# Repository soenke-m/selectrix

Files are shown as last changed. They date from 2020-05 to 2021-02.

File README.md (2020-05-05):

# selectrix

Ich baue und entwickle Hard- und Software für das Selectrix-System

Hier möchte ich gerne meine SX-Projeke  mit euch Teilen damit alle die Selectrix einsetzen wollen davon profitieren können.

Die Projekte basieren auf den Atmel ATtiny Microcontroler und sind mit Atmel Studio 7 erstellt. 
Zum Testen steht mir eine FCC zur Verfügung.

Der Nachbau und die Benutzung der Hardware geschieht auf eigene Gefahr, ich hafte nicht für Schäden, die der Anwender oder Dritte durch die Verwendung verursachen.

Alle Daten sind lizensiert unter der <a href="http://creativecommons.org/licenses/by-nc-sa/4.0/">Attribution-NonCommercial-ShareAlike 4.0 International</a>. - die eine private Weiterverwertung erlaubt, solange in angemessener Weise die Urheberschaft erwähnt wird und die abgeleitete Arbeit unter der gleichen Lizenz steht.

<a title="Mateo Zlatar / Public domain" href="https://commons.wikimedia.org/wiki/File:Open-source-hardware-logo.svg">Open-source-hardware-logo</a>

<br />Dieses Werk ist lizenziert unter einer <a rel="license" href="http://creativecommons.org/licenses/by-nc-sa/4.0/">Creative Commons Namensnennung - Nicht-kommerziell - Weitergabe unter gleichen Bedingungen 4.0 International Lizenz</a>.

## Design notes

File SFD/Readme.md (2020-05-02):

# SFD-V1-Universeller Funktionsdecoder für den SX-Bus

Verwendung:

-	Magnetartikel
-	Beleuchtung
-	Weichen
-	Signale (Haupt/Vorsignalsteuerung)
-	Bahnübergänge (mit/ohne Schranke)

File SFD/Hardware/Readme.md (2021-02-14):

Dieser Ordner enthält die Eagle Dateien

Die DIN-Stecker Version ist eine einseitige Platine

Es existiert ein <a href="https://www.reichelt.de/my/1683631">Reichel Warenkorb</a>. Die Teileliste ist für beide Versionen gültig. Die nicht benötigten Teile müssen dann gelöscht werden.

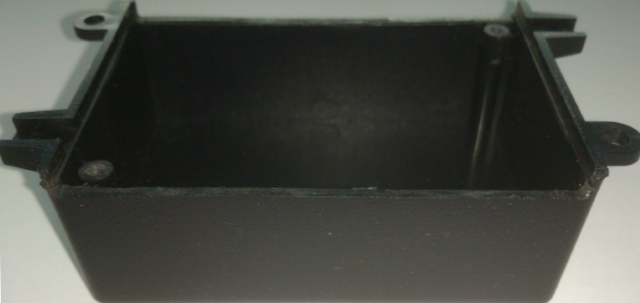
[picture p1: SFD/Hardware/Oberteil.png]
Oberteil


Das Gehäuseoberteil muss an den Längsseiten um 4mm gekürzt werden. Die Schraubendome müssen auf dieses Niveau abgefeilt werden. Die Platine wird dann zwischen beide Gehäusehälften eingeklemmt.

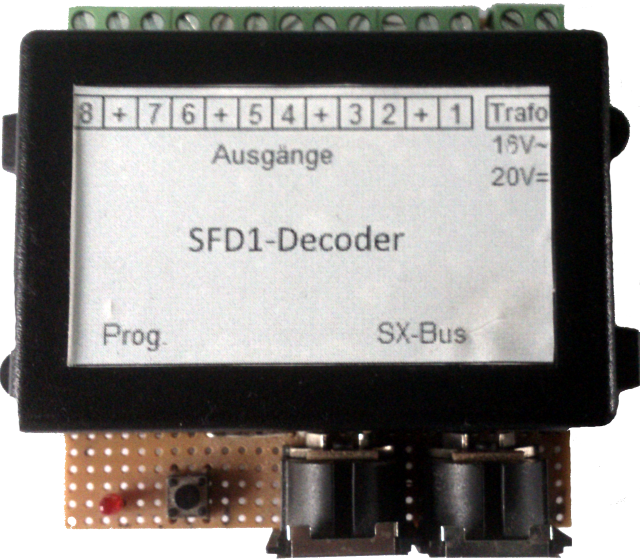
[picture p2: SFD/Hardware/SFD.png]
SFD


Das Bild zeigt noch den Prototyp mit Lochstreifenplatine.

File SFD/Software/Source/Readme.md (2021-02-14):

Die Software ist unter Atmel Studio 7.0 entwickelt und kompiliert.
Teile der Software sind aus Platz- und Geschwindigkeitsgründen in Assembler geschrieben. 
Ich hoffe die Kommentare sind verständlich.

Mit Optimierung -Os kompilieren, sonst passt der Code nicht ins Flash. 

Fuses: Interner Oszillator, Kein Clock-Div, Brown_Out_Detection 4V3.

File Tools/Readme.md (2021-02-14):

# Decoderprogramer

Dieses Tool dient zum Einstellen der Decoderparameter. Es sollte ab WinXP laufen.
Erklärung zur Bedienung stehen in der SFD-Doku. Das Programm läuft ohne Installation.

ACHTUNG !! Die Benutzung des Programms geschieht auf eigene Gefahr. Ich hafte nicht für Schäden die der Anwender oder Dritte durch die Verwendung verursachen.

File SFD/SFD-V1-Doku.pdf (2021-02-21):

Signal- u. Funktionsdecoder | SFD-V1 | Funktions- u. Parameterbeschreibung

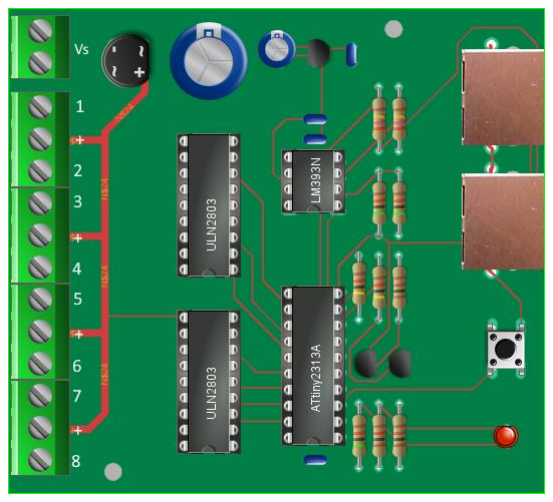
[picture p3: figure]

© 2021 Sönke Marsch | 1

SFD-V1-Universeller Funktionsdecoder für den SX-Bus

### Verwendung:

- Magnetartikel
- Beleuchtung
- Weichen
- Signale (Haupt/Vorsignalsteuerung)
- Bahnübergänge (mit/ohne Schranke)

Der SFD-V1 ist ein DIY Signal- und Funktionsdecoder. Die Platine kann in ein Kleingehäuse eingebaut werden.

Spannungsversorgung: Micro und Logik über den SX-Bus
Last Teil über Ext. – Klemmen Vss : max. 16V∿, 20V⎓
Anschlüsse: | 2 x RJ45 für den SX-Bus 1 x 2-pol. Schraubklemme für die Ext. – Stromversorgung (Vss) 4 x 3-pol. Schraubklemmen für die Ausgänge. Die Masse wird geschaltet. Die mittlere Klemme der 3er Gruppen ist mit dem Pluspol der Ext. – Stromversorgung verbunden. Ausgangsstrom max. 1 A pro Ausgang (nicht Kurzschlussfest). Max. 1,5 A alle Ausgänge zusammen.

Betriebsart:
0. 8 Schalt- / Impulsausgänge
1. 8 Schaltausgänge für Beleuchtung
2. 4 Weichen Impuls oder Dauerbetrieb
3. 2 Weichen und 1 Bahnübergang
4. 4 Blocksignale
5. 2 Einfahrsignale mit Vorsignal
6. 2 Haupt/Sperrsignale
7. 1 Einfahrsignale mit Vorsignal und 1 unabhängiges dreibegriffiges Vorsignal
8. 1 Haupt/Sperrsignal und 1 unabhängiges dreibegriffiges Vorsignal
| Ab Mode 9 mit Dunkeltastung des Vorsignals bei hp00 hp0 / sh1 des Hauptsignals
9. 1 Haupt/Sperrsignal u. 1 Blocksignal mit Vorsignal am Mast des Hauptsignal
10. 1 Einfahrsignal mit Vorsignal und 1 dreibegriffiges Vorsignal am Mast des HS
11. 1 Haupt/Sperrsignal und 1 dreibegriffiges Vorsignal am Mast des Hauptsignal

Bei allen Weichenmodi kann die letzte Weichenstellung gespeichert werden.

Alle Signal- und Bahnübergangmodi sind gedimmt (Glühlampensimulation).

Bei den Signalmodi wird nach einer Änderung erst das alte Signalbild ab gedimmt und danach das neue Signalbild auf gedimmt.

Decoderparameter:

Parameter | Wert | Mode | Bemerkungen
0 | 0 – 11 | - | Betriebsart: (Mode) | Default 2
0 | - | 8 Schaltausgänge Impuls- oder Dauerbetrieb
1 | - | 8 Schaltausgänge gedimmt (Glühlampensimulation)
| 2 | - | 4 Weichen Impuls- oder Dauerbetrieb
| 3 | - | 2 Weichen und 1 Bahnübergang
| 4 | - | 4 Blocksignale
| 5 | - | 2 Einfahrsignale mit Vorsignale
| 6 | - | 2 Haupt/Sperrsignale
7 | - | 1 Einfahrsignale mit Vorsignal und 1 dreibegriffiges Vorsignal
8 | - | 1 Haupt/Sperrsignal und 1 dreibegriffiges Vorsignal
| 9 | -

1 Haupt/Sperrsignal 1 Blocksignal mit Vorsignal am Mast des Haupt/Sperrsignal. Mit Dunkeltastung des Vorsignals

| 10 | -

1 Einfahrsignal mit Vorsignal und 1 dreibegriffiges Vorsignal am Mast des Einfahrsignals. Mit Dunkeltastung des Vorsignals

| 11 | -

1 Haupt/Sperrsignal und 1 dreibegriffiges Vorsignal am gleichen
| | | Mast mit Dunkeltastung des Vorsignals
1 | 3 – 103 | 0 – 11 | 1. Decoderadresse | Default 15
2 | 0 – 3 | 0 – 11 | 1. Subadresse | Default 0
3 | 3 – 103 | 5 – 11 | 2. Decoderadresse | Default 16
4 | 0 – 3 | 5 – 11 | 2. Subadresse | Default 0
5 | 0 – 63 | 0, 2, 3 | Impulsdauer 0 = Dauerbetrieb | Default 20 ≙ 400 ms
6 | 1 – 255 | 1 | Multiplikator für Zufallssteuerung | Default 20 ≙ 0,4 – 6,4 sek
7 | 1 – 255 | 3 | Dauer Gelbphase am Bahnübergang | Default 75 ≙ 1,5 sek
8 | 1 – 255 | 3 | Verzögerung bis Schrankenantrieb ein | Default 125 ≙ 2,5 sek
9 | 1 – 255 | 3 | Impulsdauer für Schrankenantrieb | Default 25 ≙ 0,5 sek
10 | 0 – 255 | - | Optionen: | Default 00000000
Bit 1 | 7 – 11 | 1 = Fahrstraßenabhängige Vorsignalsteuerung
Bit 2 | 5 – 11 | 1 = Alternative Ansteuerung für mehrbegriffige Signale
Bit 3 | 3 | 1 = Bahnübergang mit Lichtzeichenanlage
Bit 4 | 3 | 1 = Impulsbetrieb für Schrankenantrieb
Bit 5 | 2 + 3 | 1 = Speichern der letzten Weichenstellung
| Bit 6 | 1 | 1 = Neonleuchten-Simulation
Bit 7 | 1 | 1 = Simultansteuerung. D.h. Werte > 0 schaltet alle Lampen an
| Bit 8 | 1

1 = Zufallssteuerung. D.h. die Lampen werden zufällig eingeschaltet. Nur in Verbindung mit Simultansteuerung (Bit 7=1)
11 | 0 – 255 | 7 – 11 | Maske für fahrstraßenabh. Vorsignalsteuerung: Default 00000000
Bit 1 | 7 – 11 | Fahrstraße 1 | 0 = inaktiv, 1 = aktiv
Bit 2 | 7 – 11 | Fahrstraße 2 | 0 = inaktiv, 1 = aktiv
Bit 3 | 7 – 11 | Fahrstraße 3 | 0 = inaktiv, 1 = aktiv
| Bit 4 | 7 – 11 | Nicht benutzt
Bit 5 | 7 – 11 | Fahrstraße 1 | Bit 1 0 od. 1 aktiv
Bit 6 | 7 – 11 | Fahrstraße 2 | Bit 2 0 od. 1 aktiv
Bit 7 | 7 – 11 | Fahrstraße 3 | Bit 3 0 od. 1 aktiv
| Bit 8 | 7 – 11 | Nicht benutzt
12 | 3 – 104 | 7 – 11 | Signaladresse Standartfahrstraße | Default 17
13 | 0 – 3 | 7 – 11 | Subadresse Standartfahrstraße | Default 0
14 | 3 – 104 | 7 – 11 | Signaladresse Fahrstraße 1 | Default 18
15 | 0 – 3 | 7 – 11 | Subadresse Fahrstraße 1 | Default 0
16 | 3 – 104 | 7 – 11 | Signaladresse Fahrstraße 2 | Default 19
17 | 0 – 3 | 7 – 11 | Subadresse Fahrstraße 2 | Default 0
18 | 3 – 104 | 7 – 11 | Signaladresse Fahrstraße 3 | Default 20
19 | 0 – 3 | 7 – 11 | Subadresse Fahrstraße 3 | Default 0

Details:

Mode 0 und 2:
Wird im Parameter 5 (Impulsdauer) eine 0 eingetragen, dann wird der betreffende Ausgang dauerhaft Ein- bzw. Ausgeschaltet. Im Mode 2 ergibt sich somit ein Wechselschalter.

Mode1:
Jeder Ausgang wird mit dem korrespondierende Bit ein- bzw. ausgeschaltet. (Glühlampen) Bei Option Bit 6 = 1 wird das Einschaltflackern von Neonleuchten simuliert.
Bei Option Bit 7 = 1 werden alle Ausgänge simultan ein- bzw. ausgeschaltet. Jeder Wert > 0 auf Adr1 schaltet alle Ausgänge ein, 0 schaltet alle Ausgänge aus. Kombinierbar mit Bit 6. Bei Option Bit 8 = 1 werden alle Ausgänge zufällig eingeschaltet. Das Intervall kann über
den Multiplikator Parameter 6 zwischen 20ms … 320 ms und 5,1 sek … 81,6 sek eingestellt werden. Die Berechnung erfolgt Folgendermaßen: Zufallszahl 1 bis 16 * 20 ms * Parameter 6. Ausgeschaltet wird immer sofort. Wird nur ausgeführt wenn Bit 6 = 0 und Bit 7 = 1.

Tabelle Multiplikator Zufallssteuerung:

Mode 2 und 3:
Es ist möglich die Weichenstellung abzuspeichern (Option Bit 5 = 1). Nach dem Einschalten der Versorgungsspannung werden die Weichen nicht in die Grundstellung gebracht, sondern die letzte gespeicherte Weichenstellung wird auf den SX-Bus geschrieben.
Verhalten bei Gleisspannung AN: Änderungen zum letzten Zustand werden vorgemerkt und nach Ausschalten der Gleisspannung wird der letzte Zustand abgespeichert.
Verhalten bei Gleisspannung AUS: Bei Änderung wird sofort abgespeichert.
Dieses Verhalten verlängert die Lebensdauer des eingebauten EEPROM. Es muss nur darauf geachtet werden, dass vor dem Ausschalten der Zentrale die Gleisspannung ausgeschaltet wird. PC-Programme schalten i.d.R. die Gleisspannung beim Beenden aus.

Bei dem Bahnübergang kann statt Andreaskreuz-Blinklicht eine Rot-/Gelblicht-Ampel ausgewählt werden (Option Bit 3 = 1). Die Verzögerungszeiten bis zum Wechsel von Gelblicht auf Rotlicht, sowie bis zum Ansteuern der Schranke, können getrennt eingestellt werden.
Der Schrankenausgang kann auf Impulsbetrieb geschaltet werden (Option Bit 4 = 1). Er wird dann bei jedem Aus- und Einschalten für die eingestellte Dauer eingeschaltet. Damit kann z.B. eine Faller-Schranke #120174 über ein Relais angesteuert werden. Die Impulsdauer ist zu diesem Zweck auf 90 ≙ 1,8 sek einzustellen. Bei „POWER-ON“ wir kein Impuls generiert, um die Schranken nicht zu schließen. Dieses setzt voraus, das vor „POWER-OFF“ die Schranken geöffnet sind. Mit Option Bit 5 = 1 wird die letzte Stellung der Schranke gespeichert aber nicht auf den SX-Bus geschrieben. Wenn nach „POWER-ON“ die letzte Stellung nicht mit dem SX-Bus Wert übereinstimmt, wird die Schranke nach dem SX-Bus Wert gestellt.
Binär | Dezimal | Intervall
00000001 | 1 | 20ms ... 320ms
00001010 | 10 | 200ms … 3,2s
00011001 | 25 | 500ms … 8,0s
00110010 | 50 | 1,0s … 16s
01001011 | 75 | 1,5s … 24s
01100100 | 100 | 2,0s … 32s
01111101 | 125 | 2,5s … 40s
10010110 | 150 | 3,0s … 48s
10101111 | 175 | 3,5s … 56s
11001000 | 200 | 4,0s … 64s
11100001 | 225 | 4,5s … 72s
11111010 | 250 | 5,0s … 80s

Mode 5 bis 11:
Ansteuerung der Signale:
Standard: Option Bit 2 = 0 | Alternativ: Option Bit 2 = 1
| (Rautenhaus® SLX813N kompatibel)

Mode 7 bis 11:
Ab Mode 7 ist fahrstraßenanhängige Steuerung für das 2. Signal (Vorsignal) möglich (Option Bit 1 = 1). Die Decoderadresse 2 dient dann als Steueradresse für die Vorsignalsteuerung. Bit 1 bis 3 bzw. Bit 5 bis 7 der Steueradresse wählt die jeweilige Adresse für das 2. Signal aus. Die Auswahl geht vom MSB nach LSB d.h. ist Bit 3 (7) von Adresse 2 gesetzt wird für die Steuerung des 2. Signals die Signaladresse der 3. Fahrstraße ausgewertet, unabhängig ob Bit 2 und/oder Bit 1 der Adresse 2 gesetzt ist. Ist keines der 3 Bit gesetzt, wird die Signaladresse der Standardfahrstraße ausgewertet. Über eine Bit-Maske (Parameter 11) kann das Verhalten gesteuert werden. Bit 1 bis 3 der Maske geben an ob die jeweilige Fahrstraße berücksichtigt werden soll. Bit 5 bis 7 der Maske geben an ob das jeweilig Bit der Adresse 2 invertiert werden soll (Low aktiv) oder nicht (Hi aktiv).
Die fahrstraßenanhängige Steuerung dient dazu dem Vorsignal, in Abhängigkeit von der Weichen- oder Fahrstraßenstellung, das richtige Hauptsignal zuzuordnen. Die Decoderadresse 2 wird zu diesem Zweck auf die Adresse des Weichendecoders der Einfahrweichengruppe gesetzt, die Signaladressen der Fahrstraßen auf die Adresse der Hauptsignaldecoder der jeweiligen Fahrstraße. Das Vorsignal zeigt dann automatisch das richtige Signalbild an. Beispiel im Anhang.

Mode 9 bis 11:
Es wird, entsprechend der Hauptsignal-Stellung, das am Mast befindliche Vorsignal dunkel geschaltet. Wenn bei eingestellter Vorsignalsteuerung sich im Fahrweg kein gültiges Hauptsignal befindet (Stumpfgleis etc.) wird das Vorsignal ebenfalls dunkel geschaltet. Dieses wird dadurch erreicht, dass die korrespondierende Signaladresse der Fahrstraße auf ungültige Adresse 104 gesetzt wird.

Subadresse:
Ab Mode 2 wird zum Steuern des Decoders nur 4 Bit benötigt. Um den Adressraum besser auszunutzen wir die Adresse in 2 halb Byte sog. Nibble unterteilt. Mit Bit 1 der Subadresse wird das halb Byte der Decoderadresse ausgewählt: Bit1 = 0 ≙ Bit 1-4, Bit1 = 1 ≙ Bit 5-8.
Ab Mode 5 werden nur noch 2 Bit zum Steuern des Decoders benötigt. Zu diesem Zweck wird das halb Byte nochmals in sogenannte Dibit unterteilt. Mit Bit 2 der Subadresse wird das jeweilige Dibit ausgewählt. Je nach Bit 1 der Subadresse ist das Bit 3-4 oder Bit 7-8. Die Bits der Subadresse werden nur in den jeweiligen Betriebsmode vom Decoder berücksichtigt.

Einstellungen und Optionen:
Für alle Einstellungen und Optionen gilt: Werden sie in dem aktuellen Betriebsmode vom Decoder nicht verwendet, dann ist der Wert für den Betriebsmode unerheblich und wird bei der Verarbeitung der Daten nicht berücksichtigt.
Bit2 | Bit1 | Signalbild
0 | 0 | Hp0
0 | 1 | Hp1
1 | 0 | Sh1
1 | 1 | Hp2
Bit2 | Bit1 | Signalbild
0 | 0 | Hp0
0 | 1 | Hp1
1 | 0 | Hp2
1 | 1 | Sh1

Programmieren:

Die Programmierung des Decoders erfolgt über den SX-Bus Kanal 1 und Kanal 2.
In Kanal 1 wird die Parameternummer geschrieben. Der Decoder gibt daraufhin in Kanal 2 den aktuellen Wert des Parameters aus. Dieser kann dann überschrieben werden.
Beispiel:
In Kanal 1 wird der Wert 1 ≙ 00000001 geschrieben. Der Decoder gibt daraufhin in Kanal 2 die
1. Decoderadresse aus (Default 15 ≙ 00001111). Diese kann durch Schreiben in Kanal 2 geändert werden.

Die geänderten Werte werden sofort in den flüchtigen Speicher übernommen. Der Decoder kann dann mit den neuen Werten getestet werden, ohne den Programmier-Modus zu verlassen.
Einzige Ausnahme: Das Ändern der Funktionsart wir nur vorgemerkt und erst nach dem Verlassen des Programmier-Modus umgestellt. D.H. solange sich der Decoder im Programmier-Modus befindet, bleibt die alte Betriebsart eingestellt. Mit dem Beenden des Programmier-Modus werden die Parameter ins EEPROM des Prozessors geschrieben und wenn die Betriebsart gewechselt wurde, wird der Decoder neu gestartet (Reset). Danach steht die neue Betriebsart zur Verfügung.
Programmier-Modus ein: | - Taste am Decoder drücken.
Programmier-Modus aus: | - Taste am Decoder drücken
- Gleisspannung einschalten
Pseudo-Parameter: | - 254 lädt die Default Werte und beendet den Programmier-Modus
- 255 beendet den Programmier-Modus

Programmieren mit dem Programmiertool „DecProg.exe“:

Startfenster:
Verbinden | Gleisspg. | Monitor | Programmieren AUS

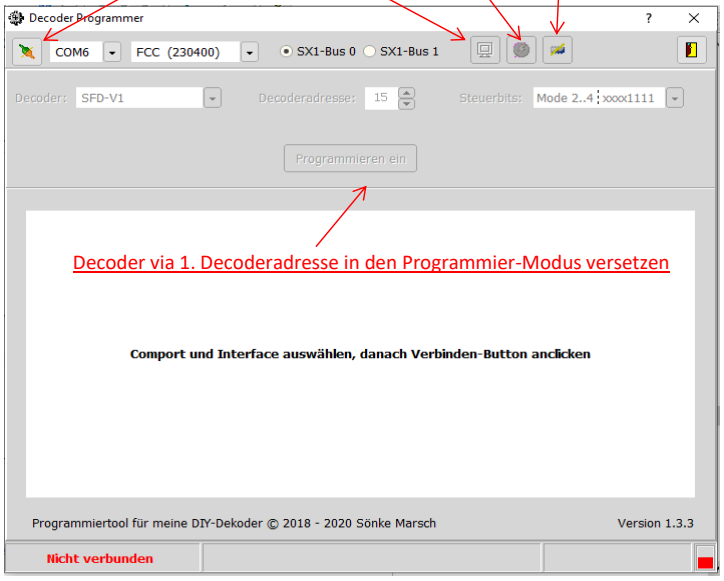
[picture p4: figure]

Decoder via 1. Decoderadresse in den Programmier-Modus versetzen

Decoder, 1. Decoderadresse und Steuerbits auswählen. Danach den „Programmieren ein“ Button drücken. Der Decoder geht dann in den Programmier-Modus, ohne das die Taste gedrückt werden muss. Das ermöglicht das Programmieren ohne unter die Anlage zu kriechen. Dieses Funktioniert aber nur, wenn sich unter der angegebenen Adresse/Subadresse nur ein Decoder gleicher Bauart befindet.

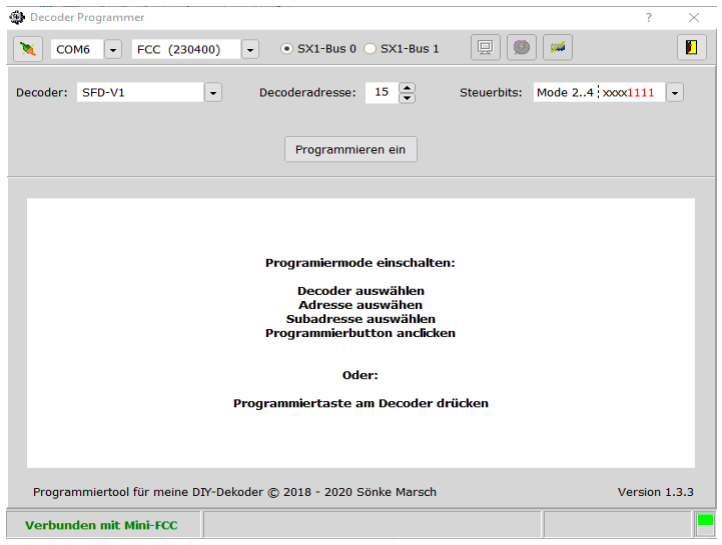
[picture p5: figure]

Unabhängig davon kann auch der Programmier-Button am Decoder gedrückt werden. Wenn das ProgTool den Decoder erkennt wird automatisch der passende Programmierdialog aufgerufen.

SFD-V1 Programmierdialog:

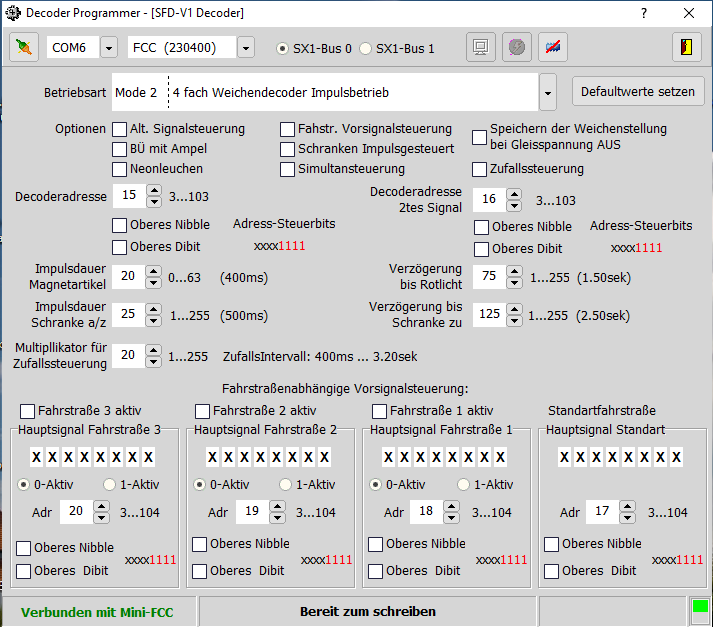
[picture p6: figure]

Alle Änderungen werden sofort zum Decoder übertragen und können noch während des Programmier-Modus im Monitorfenster getestet werden.

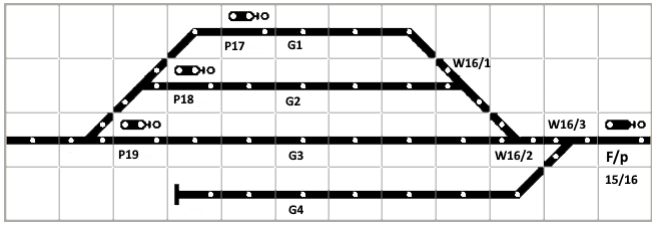
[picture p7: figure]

}

x101x111
||| |||___
||| ||____
||| |_____
|||_______
||________
|_________

Anhang:

Beispiel fahrstraßenabhängige Vorsignalsteuerung:

Entgegen der üblichen Nummerierung sind im Gleisplan bei den Signal- und Weichenbezeichnungen die SX-Bus Adressen und Bit-Nummern angegeben.

Die 2. Adresse des F/p-Signaldecoders ist identisch mit der des Weichendecoders (Adr. 16). Signaladresse Standartfahrstraße = Adr.17
Signaladresse Fahrstraße 1 = Adr.18
Signaladresse Fahrstraße 2 = Adr.19
Signaladresse Fahrstraße 3 = Adr.104 (dunkel Schalten) In die Bit Maske kommt folgender Wert:
Parameter 11 =

alle aktiv

hi aktiv
lo aktiv
hi aktiv
Szenario:
Fahrweg nach Gleis 1:
Der Wert der Adr. 16 ist xxxxx010 nach der Maskierung = xxxxx000 Keine Fahrstraße gültig, es wird die Default-Adresse ≙ genommen. Das Vorsignal p kündigt das Signalbild von P17 an.
Fahrweg nach Gleis 2:
Adr. 16 = xxxxx011 nach Maskierung = xxxxx001 Signaladresse1 aktiv. Das Vorsignal p kündigt das Signalbild von P18 an.
Fahrweg nach Gleis 3:
Adr. 16 = xxxxsx00x nach Maskierung = xxxxx01x Signaladresse2 aktiv.
Da von MSB nach LSB abgefragt wird, ist die Stellung von W16/1 unerheblich. Das Vorsignal p kündigt das Signalbild von P19 an.
Fahrweg nach Gleis 4:
Adr. 16 = xxxxx1xx nach Maskierung = xxxxx1xx Signaladresse3 aktiv.
Stellung von W16/1 u. W16/2 wird nicht berücksichtigt. Da als Signaladresse3 die Adresse 104 eingetragen ist (Stumpfgleis), wird das Vorsignal p dunkel geschaltet.

Tipp: Die Werte für die fahrstraßenabhängige Vorsignalsteuerung lassen sich übersichtlich mit dem Programmiertool eingeben.

Tabelle Impulsdauer | und Verzögerungszeiten:
Binär | Dezimal | Dauer | Binär | Dezimal | Dauer | Binär | Dezimal | Dauer
00000001 | 1 | 20 ms | 00101101 | 45 | 900 ms | 01011001 | 89 | 1780 ms
00000010 | 2 | 40 ms | 00101110 | 46 | 920 ms | 01011010 | 90 | 1800 ms
00000011 | 3 | 60 ms | 00101111 | 47 | 940 ms | 01011011 | 91 | 1820 ms
00000100 | 4 | 80 ms | 00110000 | 48 | 960 ms | 01011100 | 92 | 1840 ms
00000101 | 5 | 100 ms | 00110001 | 49 | 980 ms | 01011101 | 93 | 1860 ms
00000110 | 6 | 120 ms | 00110010 | 50 | 1000 ms | 01011110 | 94 | 1880 ms
00000111 | 7 | 140 ms | 00110011 | 51 | 1020 ms | 01011111 | 95 | 1900 ms
00001000 | 8 | 160 ms | 00110100 | 52 | 1040 ms | 01100000 | 96 | 1920 ms
00001001 | 9 | 180 ms | 00110101 | 53 | 1060 ms | 01100001 | 97 | 1940 ms
00001010 | 10 | 200 ms | 00110110 | 54 | 1080 ms | 01100010 | 98 | 1960 ms
00001011 | 11 | 220 ms | 00110111 | 55 | 1100 ms | 01100011 | 99 | 1980 ms
00001100 | 12 | 240 ms | 00111000 | 56 | 1120 ms | 01100100 | 100 | 2000 ms
00001101 | 13 | 260 ms | 00111001 | 57 | 1140 ms | 01100101 | 101 | 2020 ms
00001110 | 14 | 280 ms | 00111010 | 58 | 1160 ms | 01100110 | 102 | 2040 ms
00001111 | 15 | 300 ms | 00111011 | 59 | 1180 ms | 01100111 | 103 | 2060 ms
00010000 | 16 | 320 ms | 00111100 | 60 | 1200 ms | 01101000 | 104 | 2080 ms
00010001 | 17 | 340 ms | 00111101 | 61 | 1220 ms | 01101001 | 105 | 2100 ms
00010010 | 18 | 360 ms | 00111110 | 62 | 1240 ms | 01101010 | 106 | 2120 ms
00010011 | 19 | 380 ms | 00111111 | 63 | 1260 ms | 01101011 | 107 | 2140 ms
00010100 | 20 | 400 ms | 01000000 | 64 | 1280 ms | 01101100 | 108 | 2160 ms
00010101 | 21 | 420 ms | 01000001 | 65 | 1300 ms | 01101101 | 109 | 2180 ms
00010110 | 22 | 440 ms | 01000010 | 66 | 1320 ms | 01101110 | 110 | 2200 ms
00010111 | 23 | 460 ms | 01000011 | 67 | 1340 ms | 01101111 | 111 | 2220 ms
00011000 | 24 | 480 ms | 01000100 | 68 | 1360 ms | 01110000 | 112 | 2240 ms
00011001 | 25 | 500 ms | 01000101 | 69 | 1380 ms | 01110001 | 113 | 2260 ms
00011010 | 26 | 520 ms | 01000110 | 70 | 1400 ms | 01110010 | 114 | 2280 ms
00011011 | 27 | 540 ms | 01000111 | 71 | 1420 ms | 01110011 | 115 | 2300 ms
00011100 | 28 | 560 ms | 01001000 | 72 | 1440 ms | 01110100 | 116 | 2320 ms
00011101 | 29 | 580 ms | 01001001 | 73 | 1460 ms | 01110101 | 117 | 2340 ms
00011110 | 30 | 600 ms | 01001010 | 74 | 1480 ms | 01110110 | 118 | 2360 ms
00011111 | 31 | 620 ms | 01001011 | 75 | 1500 ms | 01110111 | 119 | 2380 ms
00100000 | 32 | 640 ms | 01001100 | 76 | 1520 ms | 01111000 | 120 | 2400 ms
00100001 | 33 | 660 ms | 01001101 | 77 | 1540 ms | 01111001 | 121 | 2420 ms
00100010 | 34 | 680 ms | 01001110 | 78 | 1560 ms | 01111010 | 122 | 2440 ms
00100011 | 35 | 700 ms | 01001111 | 79 | 1580 ms | 01111011 | 123 | 2460 ms
00100100 | 36 | 720 ms | 01010000 | 80 | 1600 ms | 01111100 | 124 | 2480 ms
00100101 | 37 | 740 ms | 01010001 | 81 | 1620 ms | 01111101 | 125 | 2500 ms
00100110 | 38 | 760 ms | 01010010 | 82 | 1640 ms | 01111110 | 126 | 2520 ms
00100111 | 39 | 780 ms | 01010011 | 83 | 1660 ms | 01111111 | 127 | 2540 ms
00101000 | 40 | 800 ms | 01010100 | 84 | 1680 ms | 10000000 | 128 | 2560 ms
00101001 | 41 | 820 ms | 01010101 | 85 | 1700 ms | 10000001 | 129 | 2580 ms
00101010 | 42 | 840 ms | 01010110 | 86 | 1720 ms | 10000010 | 130 | 2600 ms
00101011 | 43 | 860 ms | 01010111 | 87 | 1740 ms | 10000011 | 131 | 2620 ms
00101100 | 44 | 880 ms | 01011000 | 88 | 1760 ms | 10000100 | 132 | 2640 ms

Binär | Dezimal | Dauer | Binär | Dezimal | Dauer | Binär | Dezimal | Dauer
10000101 | 133 | 2660 ms | 10101110 | 174 | 3480 ms | 11010111 | 215 | 4300 ms
10000110 | 134 | 2680 ms | 10101111 | 175 | 3500 ms | 11011000 | 216 | 4320 ms
10000111 | 135 | 2700 ms | 10110000 | 176 | 3520 ms | 11011001 | 217 | 4340 ms
10001000 | 136 | 2720 ms | 10110001 | 177 | 3540 ms | 11011010 | 218 | 4360 ms
10001001 | 137 | 2740 ms | 10110010 | 178 | 3560 ms | 11011011 | 219 | 4380 ms
10001010 | 138 | 2760 ms | 10110011 | 179 | 3580 ms | 11011100 | 220 | 4400 ms
10001011 | 139 | 2780 ms | 10110100 | 180 | 3600 ms | 11011101 | 221 | 4420 ms
10001100 | 140 | 2800 ms | 10110101 | 181 | 3620 ms | 11011110 | 222 | 4440 ms
10001101 | 141 | 2820 ms | 10110110 | 182 | 3640 ms | 11011111 | 223 | 4460 ms
10001110 | 142 | 2840 ms | 10110111 | 183 | 3660 ms | 11100000 | 224 | 4480 ms
10001111 | 143 | 2860 ms | 10111000 | 184 | 3680 ms | 11100001 | 225 | 4500 ms
10010000 | 144 | 2880 ms | 10111001 | 185 | 3700 ms | 11100010 | 226 | 4520 ms
10010001 | 145 | 2900 ms | 10111010 | 186 | 3720 ms | 11100011 | 227 | 4540 ms
10010010 | 146 | 2920 ms | 10111011 | 187 | 3740 ms | 11100100 | 228 | 4560 ms
10010011 | 147 | 2940 ms | 10111100 | 188 | 3760 ms | 11100101 | 229 | 4580 ms
10010100 | 148 | 2960 ms | 10111101 | 189 | 3780 ms | 11100110 | 230 | 4600 ms
10010101 | 149 | 2980 ms | 10111110 | 190 | 3800 ms | 11100111 | 231 | 4620 ms
10010110 | 150 | 3000 ms | 10111111 | 191 | 3820 ms | 11101000 | 232 | 4640 ms
10010111 | 151 | 3020 ms | 11000000 | 192 | 3840 ms | 11101001 | 233 | 4660 ms
10011000 | 152 | 3040 ms | 11000001 | 193 | 3860 ms | 11101010 | 234 | 4680 ms
10011001 | 153 | 3060 ms | 11000010 | 194 | 3880 ms | 11101011 | 235 | 4700 ms
10011010 | 154 | 3080 ms | 11000011 | 195 | 3900 ms | 11101100 | 236 | 4720 ms
10011011 | 155 | 3100 ms | 11000100 | 196 | 3920 ms | 11101101 | 237 | 4740 ms
10011100 | 156 | 3120 ms | 11000101 | 197 | 3940 ms | 11101110 | 238 | 4760 ms
10011101 | 157 | 3140 ms | 11000110 | 198 | 3960 ms | 11101111 | 239 | 4780 ms
10011110 | 158 | 3160 ms | 11000111 | 199 | 3980 ms | 11110000 | 240 | 4800 ms
10011111 | 159 | 3180 ms | 11001000 | 200 | 4000 ms | 11110001 | 241 | 4820 ms
10100000 | 160 | 3200 ms | 11001001 | 201 | 4020 ms | 11110010 | 242 | 4840 ms
10100001 | 161 | 3220 ms | 11001010 | 202 | 4040 ms | 11110011 | 243 | 4860 ms
10100010 | 162 | 3240 ms | 11001011 | 203 | 4060 ms | 11110100 | 244 | 4880 ms
10100011 | 163 | 3260 ms | 11001100 | 204 | 4080 ms | 11110101 | 245 | 4900 ms
10100100 | 164 | 3280 ms | 11001101 | 205 | 4100 ms | 11110110 | 246 | 4920 ms
10100101 | 165 | 3300 ms | 11001110 | 206 | 4120 ms | 11110111 | 247 | 4940 ms
10100110 | 166 | 3320 ms | 11001111 | 207 | 4140 ms | 11111000 | 248 | 4960 ms
10100111 | 167 | 3340 ms | 11010000 | 208 | 4160 ms | 11111001 | 249 | 4980 ms
10101000 | 168 | 3360 ms | 11010001 | 209 | 4180 ms | 11111010 | 250 | 5000 ms
10101001 | 169 | 3380 ms | 11010010 | 210 | 4200 ms | 11111011 | 251 | 5020 ms
10101010 | 170 | 3400 ms | 11010011 | 211 | 4220 ms | 11111100 | 252 | 5040 ms
10101011 | 171 | 3420 ms | 11010100 | 212 | 4240 ms | 11111101 | 253 | 5060 ms
10101100 | 172 | 3440 ms | 11010101 | 213 | 4260 ms | 11111110 | 254 | 5080 ms
10101101 | 173 | 3460 ms | 11010110 | 214 | 4280 ms | 11111111 | 255 | 5100 ms

Zeitbasis für alle Impuls- und Verzögerungszeiten ist 20 ms

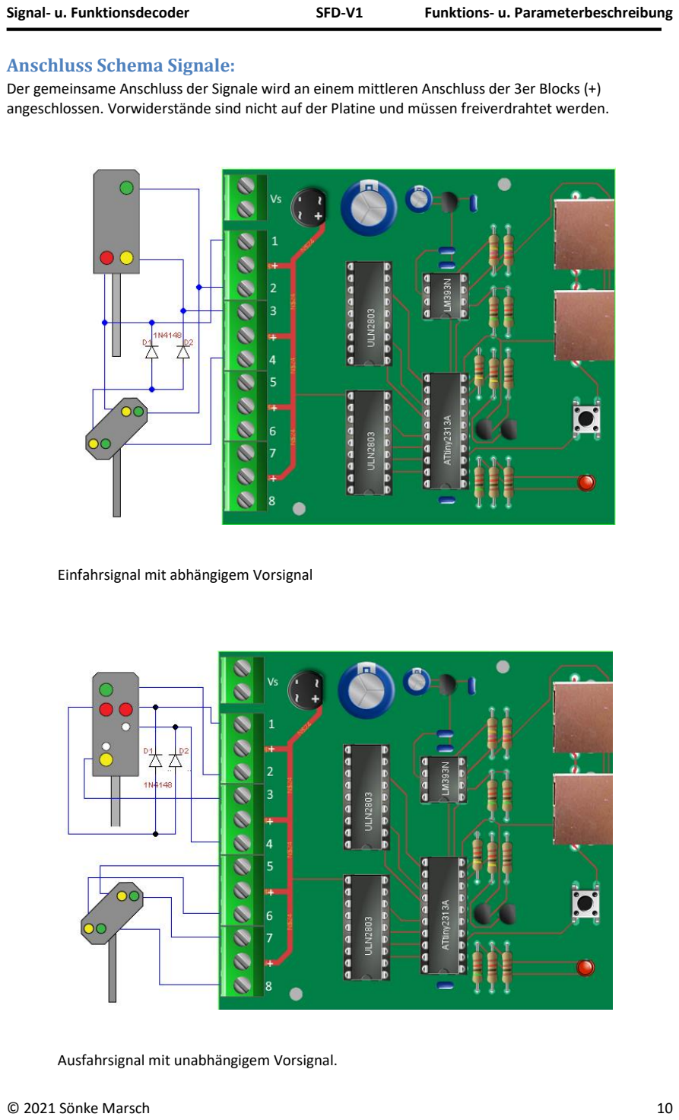
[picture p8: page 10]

### Anschluss Schema Signale:

Der gemeinsame Anschluss der Signale wird an einem mittleren Anschluss der 3er Blocks (+) angeschlossen. Vorwiderstände sind nicht auf der Platine und müssen freiverdrahtet werden.

Einfahrsignal mit abhängigem Vorsignal

Ausfahrsignal mit unabhängigem Vorsignal.

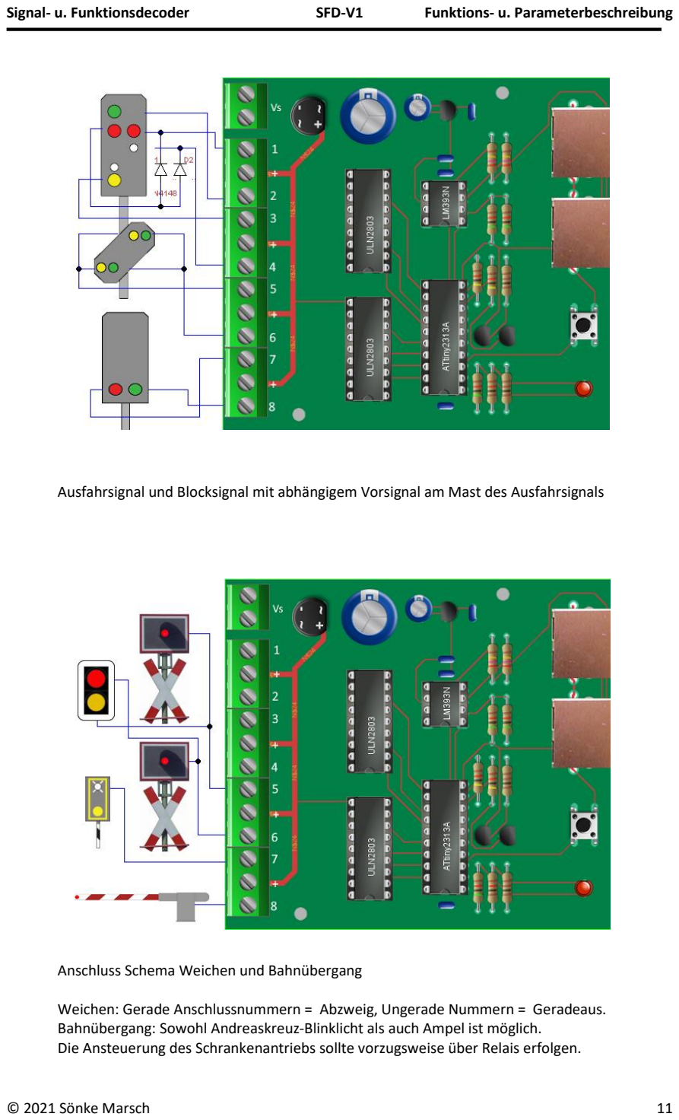
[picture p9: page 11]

Ausfahrsignal und Blocksignal mit abhängigem Vorsignal am Mast des Ausfahrsignals

Anschluss Schema Weichen und Bahnübergang

Weichen: Gerade Anschlussnummern = Abzweig, Ungerade Nummern = Geradeaus. Bahnübergang: Sowohl Andreaskreuz-Blinklicht als auch Ampel ist möglich.
Die Ansteuerung des Schrankenantriebs sollte vorzugsweise über Relais erfolgen.

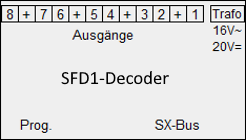
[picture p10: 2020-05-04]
SFD/Hardware/SFD-Label.png

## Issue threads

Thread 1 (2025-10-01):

Selectrix Protokoll Dokumentation

xDuinoRails, 2025-10-01:
Guten Tag, ich würde gerne auf dem RP2040 eine dreisprachige Zentrale bauen, die DCC, MM und SX spricht.

Frage:
- Wo finde ich die Spezifikation des Selectrix Protokolls?

xDuinoRails, 2025-10-02:
Danke vielmals

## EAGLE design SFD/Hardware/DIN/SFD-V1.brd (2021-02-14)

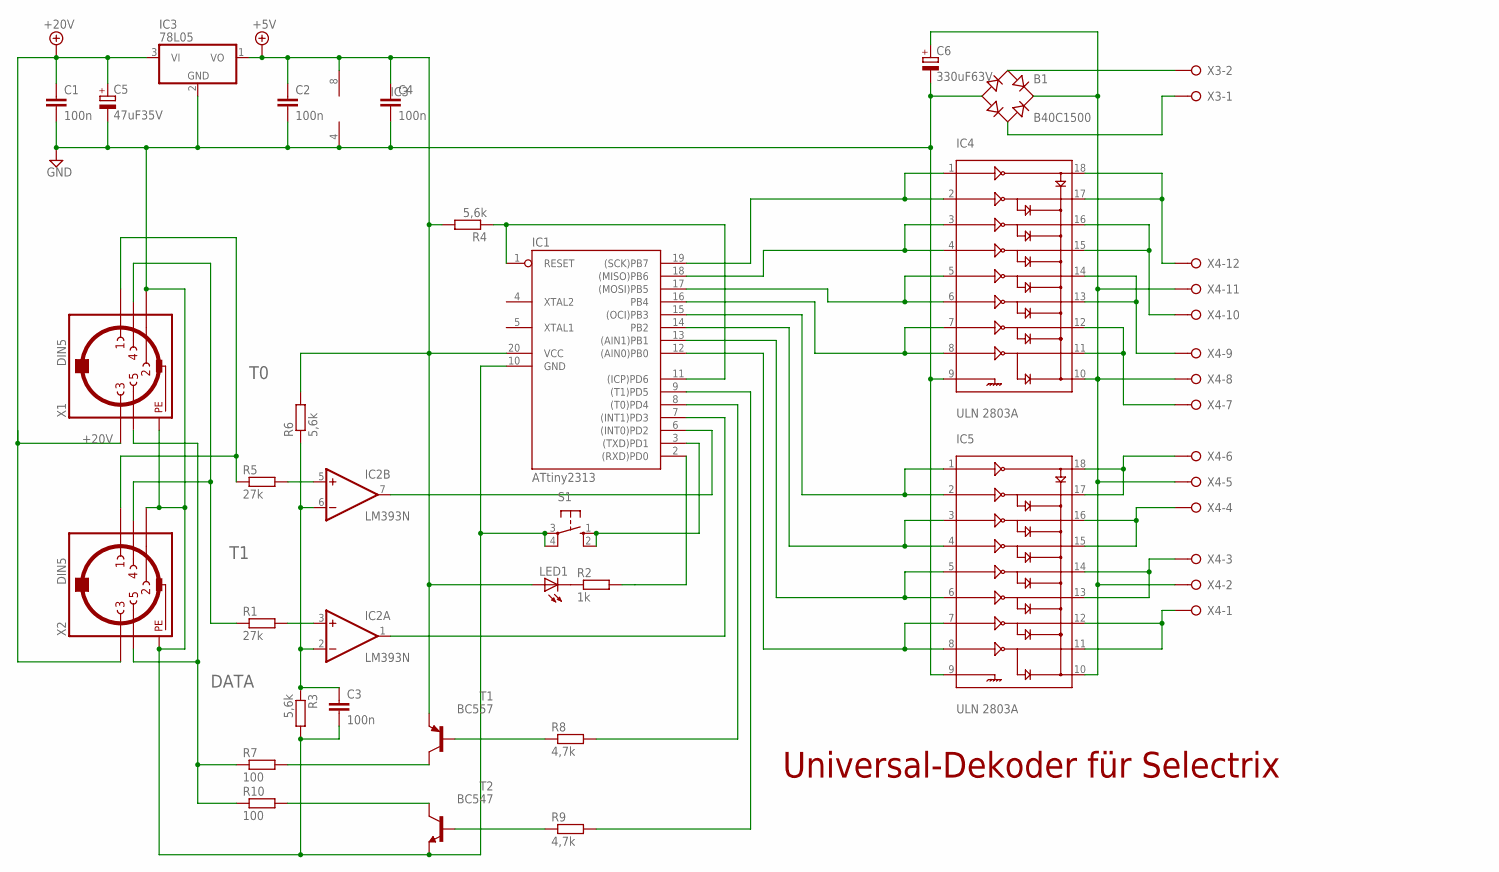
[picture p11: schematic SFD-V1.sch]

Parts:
B1: B40C1500; RB1A
C1, C2, C3, C4: 100n; C025-025X050
C5: 47uF35V; E2,5-6E
C6: 330uF63V; E5-13
IC1: ATtiny2313; DIL20
IC2: LM393N; DIL08
IC3: 78L05; TO92
IC4, IC5: ULN 2803A; DIL18
LED1: LED3MM
R1, R5: 27k; 0207/10
R2: 1k; 0207/10
R3, R4, R6: 5,6k; 0207/10
R7, R10: 100; 0207/10
R8, R9: 4,7k; 0207/10
S1: 10-XX; B3F-10XX
T1: BC557; TO92
T2: BC547; TO92
X1, X2: DIN5; CON-HIRSCHMANN_DIN5
X3: W237-02P; W237-132
X4: W237-12P

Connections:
2-INT0: IC1.6 ((INT0)PD2), IC2.7 (OUT)
4: IC1.7 ((INT1)PD3), IC2.1 (OUT)
+5V: C2.1, C4.1, IC1.20 (VCC), IC2.8 (V+), IC3.1 (VO), LED1.A, R4.2, R6.2, T1.1 (E)
+20V: C1.1, C5.+, IC3.3 (VI), X1.3, X2.3
DATA: R7.1, R10.1, X1.5, X2.5
GND: B1.-, C1.2, C2.2, C3.2, C4.2, C5.-, C6.-, IC1.10 (GND), IC2.4 (V-), IC3.2 (GND), IC4.9, IC5.9, R3.2, S1.3, S1.4 (P1), T2.1 (E), X1.2, X1.PE, X1.PE1 (PE), X1.PE@ (PE), X1.PE@1 (PE), X2.2, X2.PE, X2.PE1 (PE), X2.PE@ (PE), X2.PE@1 (PE)
unnamed: IC1.3 ((TXD)PD1), S1.1 (S), S1.2 (S1)
unnamed: IC1.8 ((T0)PD4), R8.2
unnamed: B1.AC1, X3.2
unnamed: IC2.5 (+IN), R5.2
unnamed: IC2.3 (+IN), R1.2
unnamed: LED1.K (C), R2.1
unnamed: C3.1, IC2.2 (-IN), IC2.6 (-IN), R3.1, R6.1
unnamed: IC1.2 ((RXD)PD0), R2.2
unnamed: IC1.1 (RESET), IC1.11 ((ICP)PD6), R4.1
unnamed: IC1.12 ((AIN0)PB0), IC5.7, IC5.8
unnamed: IC1.13 ((AIN1)PB1), IC5.5, IC5.6
unnamed: IC1.14 (PB2), IC5.3, IC5.4
unnamed: R10.2, T2.3 (C)
unnamed: IC1.15 ((OCI)PB3), IC5.1, IC5.2
unnamed: B1.AC2, X3.1
unnamed: R7.2, T1.3 (C)
unnamed: IC1.16 (PB4), IC4.7, IC4.8
unnamed: IC1.17 ((MOSI)PB5), IC4.5, IC4.6
unnamed: IC4.17, IC4.18, X4.12
unnamed: IC1.19 ((SCK)PB7), IC4.1, IC4.2
unnamed: IC1.18 ((MISO)PB6), IC4.3, IC4.4
unnamed: B1.+, C6.+, IC4.10, IC5.10, X4.2, X4.5, X4.8, X4.11
unnamed: IC1.9 ((T1)PD5), R9.2
unnamed: IC4.15, IC4.16, X4.10
unnamed: R8.1, T1.2 (B)
unnamed: IC4.13, IC4.14, X4.9
unnamed: R9.1, T2.2 (B)
unnamed: IC4.11, IC4.12, X4.7
unnamed: IC5.17, IC5.18, X4.6
unnamed: IC5.15, IC5.16, X4.4
unnamed: IC5.13, IC5.14, X4.3
unnamed: IC5.11, IC5.12, X4.1
T0: R5.1, X1.1, X2.1
T1: R1.1, X1.4, X2.4

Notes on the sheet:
Universal-Dekoder für Selectrix
IC3

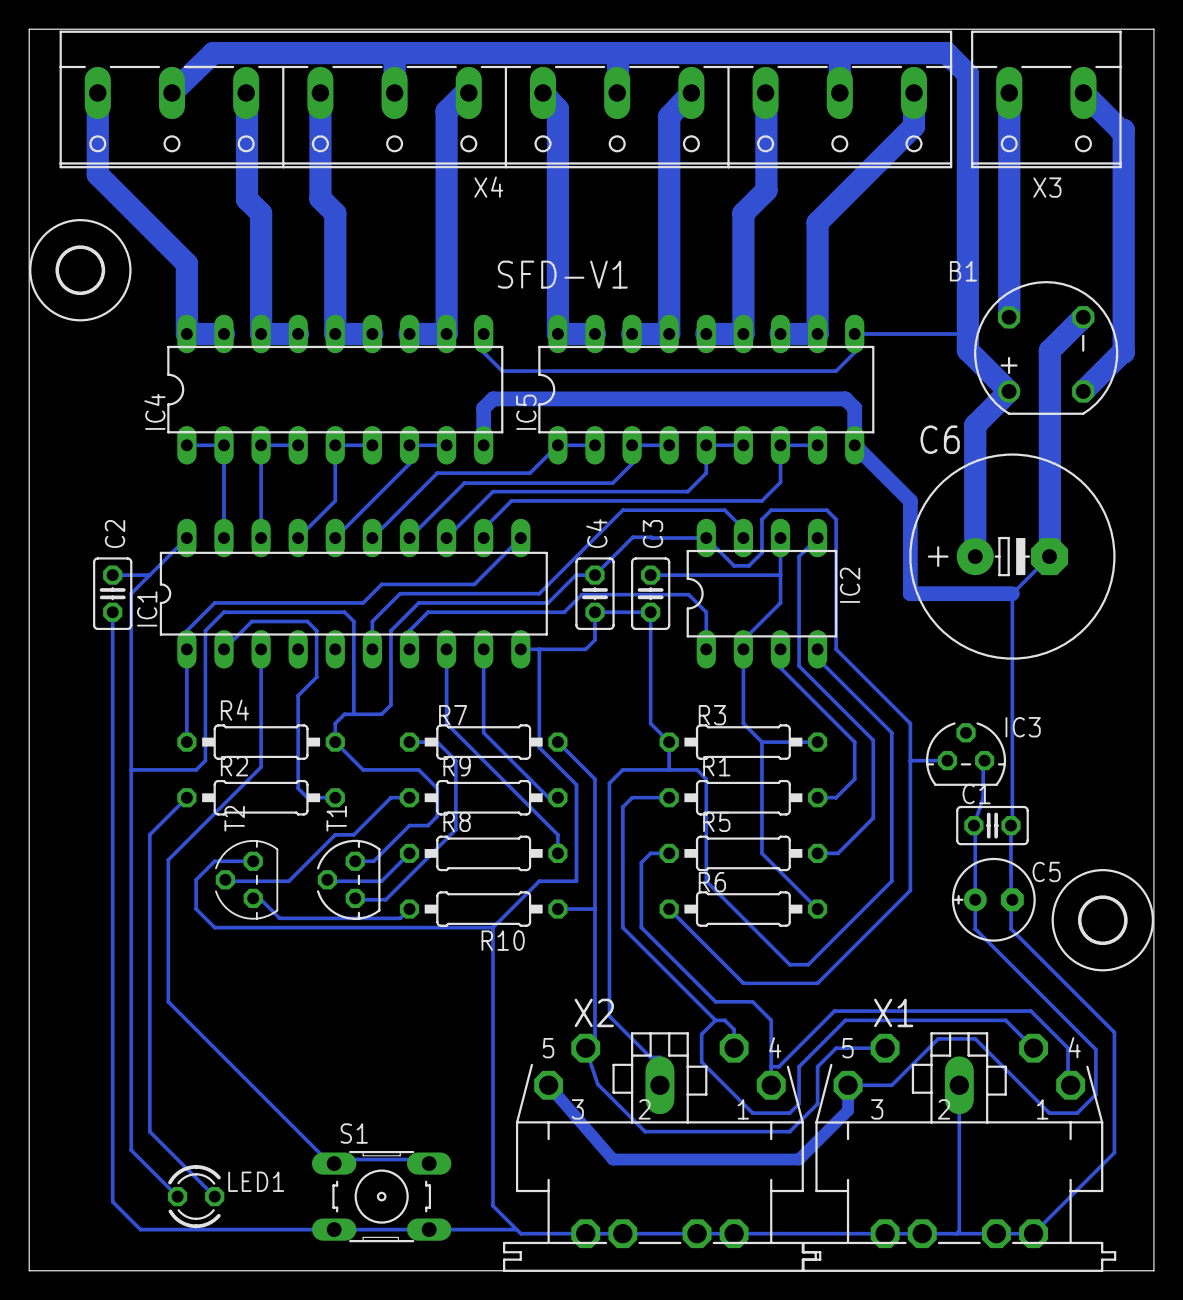
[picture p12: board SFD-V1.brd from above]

Board: 2 copper layers, 77.0 x 85.0 mm, 32 parts (0 on the bottom side), 40 nets.

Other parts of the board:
U$1, U$2: 3,0

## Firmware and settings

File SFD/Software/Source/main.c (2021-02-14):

/*
 * SFD-V1
 * Signal u. Funktionsdekoder V1
 *
 * Version 1.15
 *
 * Diese Quelldatei unterliegt der GNU General Public License,
 * die unter http://www.gnu.org/licenses/gpl.txt verfügbar ist.
 * Jede kommerzielle Nutzung, auch von Teilen, ist untersagt. 
 *
 * Copyright (c) 2018 S.Marsch
 *
 * main.c
 *
 * Created: 12.03.2018 17:56:56
 * Letzte Änderung 26.03.2020
 *
 * Author : Sönke Marsch
 *
 *	für Atmel Attiny2313A (ACHTUNG es muß der A-Type sein)
 *
 *	Fuses: Interner Oszillator, Kein Clock-Div, Brown_Out detection 4V3
 *
 *	Betriebsart:										  |------------- Option ---------------|
 *	Mode		  Decodertyp				Adr	Sub  Bit  Mam  Alt	Lza	 Sis  Lss  Nel  Sim	 Zst
 *	0: 8 fach Impuls/Schaltdecoder			 1	 N	  8	   N	N	 N	  N	   N	N    N	  N
 *	1: 8 fach Beleuchtungsdekoder			 1	 N	  8	   N	N	 N	  N	   N	J	 J	  J
 *	2: 4 fach Weichendecoder Impulsbetrieb	 1	 J	  4	   N	N	 N	  N	   J	N	 N	  N
 *	3: 2 Weichen u. 1 Bahnübergang			 1	 J	  3	   N	N	 J	  J	   J	N	 N	  N
 *	4: 4 Signale 2 Begriffig				 1	 J	  4	   N	N	 N	  N	   N	N	 N	  N
 *	5: 2 Einfahrsignale mit Vorsignal		 2	 J	  2	   N	J	 N	  N	   N	N	 N	  N
 *	6: 2 Haupt/sperrsignale					 2	 J	  2    N	J	 N	  N	   N	N	 N	  N
 *	7: 1 Einfahrsig. m. Vorsig. u. 1 VorSig. 2	 J	  2    J	J	 N	  N	   N	N	 N	  N
 *  8: 1 Haupt/sperrsignal u. 1 Vorsignal	 2	 J	  2    J	J	 N	  N	   N	N	 N	  N
 *  9: 1 Haupt/sperrsig. 1 Block HS/VS m. Dt 2	 J	  2	   J	J	 N	  N	   N	N	 N	  N
 * 10: Wie Mode7 aber mit Dunkeltastung		 2	 J	  2    J	J	 N	  N	   N	N	 N	  N
 * 11: Wie Mode8 aber mit Dunkeltastung		 2	 J	  2    J	J	 N	  N	   N	N	 N	  N
 *																			
 *	Mode2 wird zum 4 fach Wechseler, wenn Parameter 5 (Impulsdauer) = 0 ist	
 *
 */
 
#define F_CPU 8000000L
#include <avr/io.h>
#include <stdbool.h>
#include <avr/interrupt.h>
#include <avr/eeprom.h>
#include "project.h"
#include "sfd_eeprom.h"


static void wait(uint8_t delay)
{
	
	cli();
	MyDelay = delay;
	sei();
	
	while(MyDelay) ;     // warten bis MyDelay auf 0 (Dimm_ISR)
}

static void action(uint8_t pattern, uint8_t valid, uint8_t mode)
{
	cli();
	action_out(pattern, valid, mode);
	sei();
}

static void init_main(void)
{		
	//PORTA = (1<<PA0) | (1<<PA1);
	SXPORT = 0
	| (1 << PROGTASTER)		// Pullup - auf 1 setzen
	| (1 << SXTAKT)
	| (1 << SXDATA)
	| (1 << SXOUT_HI);
	
	SXDDR	= 0
	| (1<<SXOUT_LO)			// SXOUT Output
	| (1<<SXOUT_HI);				
		
	OUTDDR  = 0xFF;			// PortB: Alle Bits als Output			
	
	// Init Interrupt 0
	MCUCR = 0x01;			//jede logische Änderung an INT0-Pin erzeugt ein interrupt
	
	GIMSK = 0       
	| (1<<INT0);			// Enable INT0			
	
	 // 3000 Hz 8000000/3000-1
	 OCR1A = 2665;
	 // CTC  Prescaler 1
	 TCCR1B = 0 
	 | (1 << WGM12)
	 | (1 << CS10);
	 // Output Compare Match A Interrupt Enable
	 TIMSK  = 0 
	 | (1 << OCIE1A);
	
	eeprom_read_block(&Param, &EE_Param, sizeof(Param));
	
	CurMode = DecMode;
	init_pwm_array();
	sei();
}
static bool key_pressed(void)			
{	
	if (Prog_Pressed)
	{
		wait(DEBOUNCE);					// Taste entprellen
		if (Prog_Pressed)
		{
			while(Prog_Pressed);		// warten bis Taste losgelassen wird
			return false;
		}	
	}
	return true;	
}

void finish_program(void)
{	
	LastState = 0;
	eeprom_write_block(&Param,&EE_Param,sizeof(Param));
	
	sx_write(106,0,0xFF);				// programmieren zurücknehmen
	sx_write(105,0,0xFF);
	sx_write(104,0,0xFF);
	
	
	if (DecMode != CurMode)	Reset();
	Program_Off;
	Led_Off;
}

void start_program(void) 
{
	Led_On;
	Program_On;
	Par_Old = 127;
	
	sx_write(107,0,0xFF);
	sx_write(106,32,0xFF);				// programmieren setzen					 
	sx_write(105,MFGID,0xFF);
	sx_write(104,DEVID,0xFF);
	sx_write(0,0,0xFF);					// acknowledge für ProgTool
	
	wait(KEYLOCK);
}

void do_program(void)
{
	uint8_t par;
	uint8_t data;
	bool	store;
	uint8_t pdata;
	
	data = sx_read(2);
	par = sx_read(1);
	
	pdata = par > sizeof(Param) - 2 ? 0 : Param[par];
	store = false;
	switch(par)
	{
		case 0:								// Decodermode
			if (data < 12) store = true;	// nur Mode 0 bis 11
			break;
		case 1:								// Adr1
		case 3:								// Adr2
			if ((data < 104) && (data > 2)) store = true; // nur Adresse 3 bis 103
			break;
		case 2:								// SubAdr1
		case 4:								// SubAdr2
		case 13:							// Multi-SubAdr0
		case 15:							// Multi-SubAdr1
		case 17:							// Multi-SubAdr2
		case 19:							// Multi-SubAdr3
			if (data < 4) store = true;		// Subadresse nur 0 bis 3
			break; 
		case 5:								// ImpTime
			if (data < 64) store = true;	// nur Bit 0-5 (0-63)
			break;
		case 6:								// TimeRatio
		case 7:								// RedDelay
		case 8:								// BarDelay
		case 9:								// BarImpTime
			if (data > 0) store = true;		// Zeitsteuerungsteuerung nur 1-255
			break;
		case 10:							// OptSw
		case 11:							// Multiadressmaske
			store = true;
			break;
		// Ungültige Adresse 104 = Vorignal dunkel
		case 12:							// Multi-Adr0
		case 14:							// Multi-Adr1
		case 16:							// Multi-Adr2
		case 18:							// Multi-Adr3
		if ((data < 105) && (data > 2)) store = true; // nur Adresse 3 bis 104
		break;
		default:
			break;
	}
	if ((store) && (par == Par_Old))
	{
		if (data != pdata)
		{
			Param[par] = data;				// Neuen Parameterwert speichern
			sx_write(0,0,0xFF);				// acknowledge für ProgTool
			init_pwm_array();
		}
	} else
	{
		sx_write(2,pdata,0xFF);				// Aktuellen Parameterwert auf den SX-Bus schreiben
		sx_write(0,0,0xFF);					// acknowledge für ProgTool
		
		if (par > 253)						// Pseudoparameter beenden daa Programmieren
		{
			// 254 = Werkseinstellung laden und beenden, 255 = nur beenden
			if (par == 254) eeprom_read_block(&Param, &EE_Default, sizeof(Param));
			finish_program();	
		}
	}
	Par_Old = par;
}

int main(void)
{
	uint8_t state;
	uint8_t mode;
	uint8_t adr;
	uint8_t sub;
	uint8_t maske;
	uint8_t laststate1;
	uint8_t laststate2;
	
	init_main();
	mode = CurMode;
	adr = Adr1;
	if (LastState & 0x80)
	{	// Letzte Weichenstellung auf SX-Bus schreiben 
		// nur wenn LS_OK-Flag (Bit7 = 1) gesetzt ist
		state = LastState & 0x0F; 
		laststate1 = state;
		maske = 0x0F;
		if (mode == 3) maske = 0x03;
		if bitRead(SubAdr1,0)
		{
			swapNibble(laststate1);
			swapNibble(maske);
		}
		sx_write(adr,laststate1,maske);
	} else
	{	// Adresse x 2 = Wartezeit,damit nicht alle Dekoder auf einmal schalten
		wait(adr << 1);
		state = 0;						//Signale HP0 / Weichen alle gerade
		
		// Ports in Grundstellung bringen
		(mode < 2) ? action(state,0xFF,mode) : action(state,0x0F,mode); 
		if (mode > 4) action(state,0xF0,mode);	// 2. Signal extra
	}
	laststate1 = state;
	laststate2 = 0;
	bitSet(FLAG,Boot_Ok);				// Booten beendet
	seed = shiftreg_lo;					// Zufallszahl initialisieren
    while (1)
	{
		adr = Adr1;
		sub = 0;
		state = sx_read(adr);
		// bei Mode1 und Simultansteuerung schalten Werte > 0 alle Ports ein
		if ((bitRead(PSW,Sim)) && (state) && (mode == 1)) state = 0xFF;
		if (mode > 1)
		{
			sub = SubAdr1;
			if bitRead(sub,0) swapNibble(state);
			state &= 0x0F;
			if (mode == 3) state &= 0x07; // nur die untern 3 Bits
			if (mode > 4)
			{
				if bitRead(sub,1) state >>= 2;	// obere Dibits nutzen ?
				state &= 0x03;					// dann Bit 3..2 --> Bit 1..0
			}
		}
		if (state != laststate1)
		{
			StateChange_On;					// Änderung merken
			action(state, state ^ laststate1, mode);
			laststate1 = state;
		}
		if (GleisSpg)
		{
			if (Programing) finish_program();
		} else
		{	// nur bei GleisSpg AUS programmieren oder letzte Stellung speichern
			if (check_prg_req(key_pressed(), adr, sub) == 0)
			{
				(Programing) ? finish_program() : start_program();
			}
			if (StateChange)				// nur wenn sich was geändert hat speichern
			{
				StateChange_Off;			// Änderung zurücknehmen
				// Nur Mode2 u. 3 Letzte Weichenstellung speichen mit gesetzten LS_OK-Flag (Bit7 = 1)
				if ((SaveLastState) && ((mode == 2) || (mode == 3))) eeprom_write_byte(&EE_LastState,state | 0x80);	
			}
		}
		if (Programing) do_program();
		if (mode > 4)					// 2. Adresse
		{
			adr = Adr2;
			sub = SubAdr2;
			if ((MultiAdrMode) && (mode > 6))
			{
				adr = sx_read(adr);			// Masteradresse lesen
				maske = MulMask;
				if (sub) swapNibble(adr);	
				adr ^= ~maske;				// Low od. High-Aktiv prüfen
				swapNibble(maske);		
				adr &= maske;				// nur die Aktiven ausfiltern
				if (adr & 0x07)				// nur die unteren 3 Bit
				{
					// Die zur Fahrstrasse/Weichenstellung passende
					// Hauptsignaladresse auswählen
					if bitRead(adr,2)		
					{
						adr = MulAdr3;
						sub = MulSubAdr3;
					} else if bitRead(adr,1)
					{
						adr = MulAdr2;
						sub = MulSubAdr2;	
					} else 
					{
						adr = MulAdr1;
						sub = MulSubAdr1;
					} // endif BitRead
				} else
				{
					// Keine aktiv, dann Defaultadresse
					adr = MulAdr0;
					sub = MulSubAdr0;
				} // endif adr
			} // endif MultiAdrMode
			// Kein gültiges Haupsignal im Fahrweg?
			if (adr == 104) {
				bitClear(FLAG,Vs_Ok);
				state = 0;
			}
			else {
				bitSet(FLAG,Vs_Ok);
				state = sx_read(adr);
			}
			if bitRead(sub,0) swapNibble(state);
			if bitRead(sub,1) state >>= 2;
			state &= 0x03;
			if (mode == 9) state &= 0x01;
			if (state != laststate2)
			{
				action(state, 0xF0, mode);
				laststate2 = state;
			}	
		} // endif Mode > 8
    } // end While
}

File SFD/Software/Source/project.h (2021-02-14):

/*
 * SFD-V1
 * Signal u. Funktionsdekoder V1
 * 
 * Diese Quelldatei unterliegt der GNU General Public License,
 * die unter http://www.gnu.org/licenses/gpl.txt verfügbar ist.
 * Jede kommerzielle Nutzung, auch von Teilen, ist untersagt.
 *
 * Copyright (c) 2018 S.Marsch
 *
 * Header File project.h
 *
 * Created: 18.03.2018 11:12:44
 * Letzte Änderung 06.02.2021
 *
 *  Author: Sönke Marsch
 */ 


#ifndef PROJECT_H_
#define PROJECT_H_
#include <avr/io.h>

// Hersteller ID 1..255
#define MFGID			0xF8		// Meine ID
// Dekoder ID 1..127 (Bit 7 reserviert)
#define DEVID			0x01		// SFD-Decoder

// Definition für die DIMM-Engine
// für weitere Informationen siehe "sxtiny.S" Datei

#define PWM_STEPS		60			// Dimmstufen
#define DIMM_VAL_MIN	100			// aktiver Bereich 100-160
#define DIMM_VAL_MAX	161			// 
#define DIMM_UP_SPEED	6			// Auf- und Abdimmgeschwindigkeit = 200mS
#define DIMM_DOWN_SPEED	5			// für Glühlampen-Simulation = 240mS
#define DIMM_UP_DELAY	23			// Aufdimmverzögerung für neue Signalbilder = 460mS
#define BLINK_TIME		25			// = 500ms Blinkdauer Andreaskreuz


// SX-Portbits
// PORTD:
#define LED				0			// Output, Status-LED
#define PROGTASTER		1			// Input Pull-Up
#define SXTAKT			2			// SX-T0, muß INT0-Pin sein
#define SXDATA			3			// SX-T1
#define SXOUT_HI		4			// SX-Data High
#define SXOUT_LO		5			// SX-Data Low
#define RESET			6			// Software Reset

// FLAG's
#define Gleisbit		7			// 1 = Gleisspannung ein
#define Prog			6			// 1 = Decoder im Programmiermodus
#define Boot_Ok			5			// 1 = Bootvorgang beendet
#define Change			4			// 1 = Adresse1-Daten geändert
#define Vs_Ok			3			// 1 = Gültiges Hautsignal für Vorsignalsteuerung (nur MultiAdressMode)
#define req				2			// 1 = Schreiben/Lesen anfordern
#define adr_ok			1			// 1 = Adresse komplett, ab jetzt Daten schreiben/lesen
#define base_ok			0			// 1 = Syncronisation und Basisadresse erkannt
 
 // Parameter-Schalter 
 // PSW
#define Mam				0			// Multiadressmodus nur Signal-Mode 9-11
#define Alt				1			// Multibitmodus (2/4 Bit Steuerung der Signale) Mode 8-11
#define Lza				2			// Lichtzeichenanlage (Bahnübergang mit Gelb/Rot-Ampel)
#define Sis				3			// Schrankenimpulssteuerung (für ein und aus je ein Impuls)
#define Lss				4			// Laststatesave (speichern der letzten Weichenstellung) Mode2-3
#define Nel				5			// Neonlampen-Simulation
#define Sim				6			// Simultanansteuerung der Ausgänge
#define Zst				7			// Zufallsteuerung beim Einschalten

#ifdef __ASSEMBLER__
	// Registervorgaben
	#define rzero			r1		// Null-Register wird vom GCC auf 0 gesetzt
	#define	ssave			r2		// Sicherungsregister für Statusport SX-ISR
	#define shiftreg_lo		r3		// Schieberegister für Sync und Basisadresse
	#define shiftreg_hi		r4
	#define bitcounter		r5		// Zähler für Unteradresse
	#define vbuffer			r6		// Schreib/Lesepuffer
	#define vmaske			r7		// Schreibmaske
	#define sisr			r8		// Sicherungsregister für Statusport PWM-ISR
	#define cur_dimm		r9		// akt. Dimmwerte ( 100-160)
	#define myrest			r10		// Zähler für sequenzielles Schalten
	#define seed			r11		// Zufallszähl
	
	
	
	// Portdefinition
	// PORTB = 8bit OutPort
	#define OUTPORT		_SFR_IO_ADDR(PORTB)
	#define INPORT		_SFR_IO_ADDR(PINB)

	// PORTD = SX-Bus
	#define SXPIN		_SFR_IO_ADDR(PIND)
	#define SXPORT		_SFR_IO_ADDR(PORTD)
	#define SXDDR		_SFR_IO_ADDR(DDRD)
	
	// Variablen	
	#define FLAG		_SFR_IO_ADDR(GPIOR0)
	#define SBUFFER		_SFR_IO_ADDR(GPIOR1)
	#define SMASKE		_SFR_IO_ADDR(GPIOR2)
	#define DIMM_DIR	_SFR_IO_ADDR(USIDR)
	#define PSW			_SFR_IO_ADDR(UBRRL)
	
	// EQU'S
	#define _SREG		_SFR_IO_ADDR(SREG) 
	#define _TIMSK		_SFR_IO_ADDR(TIMSK)
	#define _TIFR		_SFR_IO_ADDR(TIFR)
	#define _EEAR		_SFR_IO_ADDR(EEAR)
	#define _EECR		_SFR_IO_ADDR(EECR)
	#define _EEDR		_SFR_IO_ADDR(EEDR)
#else
	// Registervorgaben								____
	register uint8_t ssave			asm("r2");	//		|
	register uint8_t shiftreg_lo	asm("r3");	//		|
	register uint8_t shiftreg_hi	asm("r4");	//		|
	register uint8_t bitcounter		asm("r5");	//		|
	register uint8_t vbuffer		asm("r6");	//		|----->	Registergebundene Variablen 
	register uint8_t vmaske			asm("r7");	//		|		benutzt in "asm" (sxtiny.S)
	register uint8_t sisr			asm("r8");	//		|	
	register uint8_t cur_dimm		asm("r9");	//		|
	register uint8_t myrest			asm("r10");	//		|
	register uint8_t seed			asm("r11");	//	____|
	
	// PORTB = 8bit OutPort
	#define OUTPORT		PORTB
	#define INPORT		PINB
	#define OUTDDR		DDRB
	
	// PORTD = SX-Bus
	#define SXPIN		PIND
	#define SXPORT		PORTD
	#define SXDDR		DDRD
	
	// Variablen
	#define FLAG		GPIOR0
	#define PSW			UBRRL
	
	#define DEBOUNCE		5			// Tastenentprellung 100ms
	#define KEYLOCK			25			// Totzeit nach Tastendruck 500 ms
	
	// Macro's für die Bitmanipulation
	#ifndef cbi
	#define cbi(sfr, bit) (_SFR_BYTE(sfr) &= ~_BV(bit))
	#endif
	#ifndef sbi
	#define sbi(sfr, bit) (_SFR_BYTE(sfr) |= _BV(bit))
	#endif
	#define bitRead(value, bit) (((value) >> (bit)) & 0x01)
	#define bitSet(value, bit) ((value) |= (1UL << (bit)))
	#define bitClear(value, bit) ((value) &= ~(1UL << (bit)))
	#define swapNibble(value) (value = (value<<4) | (value>>4))
	
	#define SaveLastState	bitRead(PSW,Lss)				// Letzte Stellung speicher ja/nein (Mode 2 u. 3)
	#define MultiBitMode	bitRead(PSW,Mbm)				// Steuerung Sh1 abhängig von Fahrstrasse (ab Mode 7)
	#define MultiAdrMode	bitRead(PSW,Mam)				// Fahrstrassenabhängige Vorsignalsteuerung (ab Mode 8)
	#define StateChange		bitRead(FLAG, Change)			// Änderung der letzten Decoder Stellung
	#define StateChange_On	bitSet(FLAG, Change)
	#define StateChange_Off	bitClear(FLAG, Change)
	#define Program_On		bitSet(FLAG, Prog)				// Programmieren einschalten
	#define Program_Off		bitClear(FLAG, Prog)			// Programmieren ausschalten
	#define Programing		bitRead(FLAG, Prog)				// programmieren ein/aus
	#define GleisSpg		bitRead(FLAG, Gleisbit)			// Gleisspannung ein/aus
	#define Prog_Pressed	!bitRead(SXPIN, PROGTASTER)		// Programmiertaster gedrückt = 1
	#define Led_On			bitSet(SXDDR, LED)				// LED einschalten
	#define Led_Off			bitClear(SXDDR, LED)			// LED ausschalten
		
	// Hardwarereset
	static inline void Reset() __attribute__((always_inline));
	void Reset()
	{
		bitSet(SXDDR, RESET);
	}
	
	// Parameter-Array
	uint8_t Param[21];
	// Zugriff über Namen definieren
	#define DecMode		Param[0]
	#define Adr1		Param[1]
	#define SubAdr1		Param[2]
	#define Adr2		Param[3]
	#define SubAdr2		Param[4]
	#define ImpTime		Param[5]
	#define TimeRatio	Param[6]
	#define RedDelay	Param[7]
	#define BarDelay	Param[8]
	#define BarImpTime	Param[9]
	#define OptSw		Param[10]
	#define MulMask		Param[11]
	#define MulAdr0		Param[12]
	#define MulSubAdr0	Param[13]
	#define MulAdr1		Param[14]
	#define MulSubAdr1	Param[15]
	#define MulAdr2		Param[16]
	#define MulSubAdr2	Param[17]
	#define MulAdr3		Param[18]
	#define MulSubAdr3	Param[19]
	#define LastState	Param[20]
	
	
	volatile uint8_t MyDelay;		// wir alle 18mS decremented
	volatile uint8_t CurMode;
	uint8_t Par_Old;
	
	extern uint8_t check_prg_req(uint8_t key, uint8_t adr,uint8_t subadr);
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

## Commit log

2020-05-01 SFD-Projekt hinzugefügt
    [SFD_N.brd, SFD_N.sch]
2020-05-01 Bug beseitigt (falsche Pinzuordnung)
    [project.h]

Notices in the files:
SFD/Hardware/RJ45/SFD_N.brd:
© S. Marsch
